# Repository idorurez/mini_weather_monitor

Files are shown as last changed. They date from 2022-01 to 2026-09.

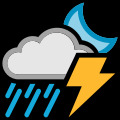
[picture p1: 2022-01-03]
sdcard/47_120x120.jpg

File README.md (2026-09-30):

# Amefuriko — Mini Weather Monitor

After using a really crappy indoor temp and humidity monitor, I wanted to build one for myself to see if I could do better. This is the result. Is it better? I have no idea, but at least it also has a forecast I can trust, built the way I like.

## What it does

* Indoor temperature (°F), humidity, and pressure from a BME280, refreshed every 60 seconds
* Date and time, synced over NTP
* Two-day forecast from Weather Underground: today and tomorrow, with a big icon showing today's weather (sun, clouds, rain, etc.)
* Backlight that follows the room: a BH1750 ambient light sensor drives PWM with smooth ramping, no stepped jumps

## Hardware

* ESP32 devkit (ESP-WROOM-32)
* 4" 480x320 TFT, ST7796 over SPI, run in portrait (320x480)
* BME280 (temp / humidity / pressure) and BH1750 (ambient light) on I2C
* Micro SD card on its own VSPI bus
* Custom PCB and schematic in `pcb/` (KiCad), 3D-printed stand/case models in `model/` (SolidWorks)

Pin map lives in `src/User_Setup.h`. TFT on MOSI 13 / SCLK 14 / CS 15 / DC 26 / RST 32, backlight on GPIO 4 (PWM). SD on VSPI: MOSI 23 / MISO 19 / SCLK 18 / CS 5.

## SD card contents

Everything in `sdcard/` goes on the card root:

* `kozgoprobold*.vlw` — Kozuka Gothic Bold smooth fonts, the UI typeface
* `*_120x120.jpg` — weather icons, named by Weather Underground icon code
* `weather.cfg` — your secrets and location (below). Not in the repo on purpose.

## Configuration

`/weather.cfg` on the SD card, JSON:

```json
{
  "wu_api_key": "your weather underground key",
  "zip": "94070",
  "station_id": "",
  "WIFI": { "hostname": "yokai", "ssid": "your-ssid", "pass": "your-password" },
  "LOCATION": { "latitude": "37.50", "longitude": "-122.34" }
}
```

## Build and flash

PlatformIO project (`platformio.ini` targets `esp32dev`, Arduino framework). Build and upload from VS Code with PlatformIO, or:

```
pio run -t upload
```

Serial monitor at 115200 baud.

## Layout

* `src/` — firmware
* `pcb/` — KiCad schematic and PCB
* `model/` — SolidWorks case/stand models plus a gcode
* `sdcard/` — fonts, weather icons, and config that live on the SD card

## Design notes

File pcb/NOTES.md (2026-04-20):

# PCB Design Notes

Captures intentional design choices and debugging history that aren't
obvious from the schematic alone, plus a TODO list for the next revision.

## Intentional design choices (not bugs)

### J1 wired to UART0 (GPIO1 / GPIO3)
J1 routes the dev kit's `RX0` and `TX0` pins to a 2-pin external header.
This is the **same** UART that the dev kit's onboard CP2102 is permanently
soldered to. Two USB-UARTs on those lines fight each other.

This is **intentional**, not a bug — the convention is: only one of
{onboard CP2102 USB, J1 external UART} should be plugged into a host
at a time. Use one or the other for serial / flashing.

If that convention ever needs to be relaxed (e.g. flash via J1 while
also keeping the onboard USB attached for power), move J1 to
`GPIO16/GPIO17` (RX2/TX2 — currently unconnected per the netlist) and
switch firmware to `Serial2.begin(...)`.

### Two USB-C breakouts (horizontal + vertical)
Both `adafruit_type_c_breakout_rev_b1` (horizontal) and
`adafruit_type_c_vertical_breakout1` (vertical) footprints are placed
intentionally as **mounting alternates**:

- **Horizontal**: desk use; the unit leans on the USB plug.
- **Vertical**: hanging the unit on a wall.

Pick one at assembly time and only solder that one. Both have D+/D-
deliberately unconnected — the breakouts are power-only, since serial /
programming goes through the dev kit's own micro-USB (or J1).

## Power architecture history

The redundant-looking power components (U1 = Pololu S13V30F5,
U3 = Pololu U3V70F5, plus Q1 IRLML6402 P-MOSFET, D1 1N5819 Schottky,
`sj_mini_3v3` jumper) are the result of several revs of brownout / reset
debugging:

- **Brownouts traced partly to mechanical interference**: the TFT's
  on-display SD-card shield was physically touching one of the
  decoupling capacitors on the carrier PCB, causing intermittent
  shorts / brownouts. **Mechanical fix on next rev**: shim or relocate
  the offending cap so it sits well clear of the SD shield's metal
  frame.
- **Multiple regulator footprints** were placed because the Pololu
  modules are expensive and sometimes go out of stock. Having an
  alternate populatable regulator means the board can be assembled
  with whichever is available without a spin.
- **Open solder jumpers** (`sj_Open_onboard_sdcard_*`,
  `sj_onboard_sdcard_clk`) were attempts to wire up the TFT module's
  *own* on-display SD card slot. **Never got it working.** Leave them
  open or remove from next rev to reduce confusion — the project uses
  a separate SD card on VSPI (GPIO5/18/19/23) instead. Forensic
  analysis of why it never mounted is in the section below.

## Why the TFT's onboard SD never mounted

How it was wired (closing the four solder jumpers JP6-JP9 routes the
TFT module's onboard SD card pins to the same ESP32 GPIOs as the
standalone SD on VSPI):

| TFT pad | Jumper | ESP32 GPIO |
|---|---|---|
| `SD_CS` 15 | JP8 | GPIO5 |
| `SD_MOSI` 16 | JP6 | GPIO19 |
| `SD_MISO` 17 | JP7 | GPIO23 |
| `SD_SCK`  18 | JP9 | GPIO18 |

That maps to `User_Setup.h` (`SD_PIN=5, SD_MOSI=23, SD_MISO=19,
SD_SCLK=18`). Firmware-side it should "just work" — TFT itself is on
HSPI (`USE_HSPI_PORT`), SD on VSPI, no bus conflict. So the failure
is hardware-side. Most likely culprits, ranked:

1. **No pull-ups on the SD lines.** SD-mode requires 10-50 kΩ pull-ups
   to 3.3V on `CS`, `MOSI`, `MISO`, `SCK`. None present on the JP6-JP9
   nets in this design, and cheap MSP4021 modules typically don't add
   them on the SD socket either. Without pulls, the card may never
   respond to init — exact symptom: `SD.begin()` returns false.
2. **MISO not tri-stated by the TFT module's onboard SD socket.**
   Notorious gotcha on this class of TFT — the SD's `DO` (MISO) line
   is wired straight to the connector with no tri-state buffer, so the
   card holds the line even when CS is high. Standard fix is a 74HC125
   buffer on MISO.
3. **Brownouts during SD inrush** (~100-300 mA). Same family of issue
   as the documented brownout history. Lacks bulk decoupling near the
   TFT VCC pin.
4. **Solder-jumper reliability** — four hand-bridged SJ pads in series
   on the SD signals; one cold joint kills the whole path. Hard to
   diagnose without per-jumper LEDs/test points.
5. **VSPI default-instance edge cases** — usually fine but worth
   passing an explicit `SPIClass` to `SD.begin()` if revisiting.

### If the TFT-SD path is ever revisited (next rev)
- Add **10 kΩ pull-ups to 3.3V on CS, MOSI, MISO, SCK** between the
  jumpers and the ESP. Single biggest payoff.
- Add a **74HC125 tri-state buffer on MISO** between the TFT module and
  the ESP. Decouples the SD's bad MISO behavior from the bus.
- **Generous decoupling on TFT VCC**: 10 µF tantalum + 100 nF ceramic
  right at TFT pin 1, plus 22 µF on the 3.3V rail near the SD jumpers.
- **Replace solder jumpers with 0Ω resistors or a DIP switch** so
  contact is reliable.

(Practical note: the standalone SD module already works fine for this
project; the TFT-SD path is forensic curiosity, not a real blocker.)

## TODO for next PCB rev

### Strapping-pin pull resistors
- [ ] **10kΩ pull-up on GPIO15 (TFT_CS) to 3.3V.** Without it, GPIO15
      can be low at power-on, which suppresses the ROM bootloader's
      diagnostic log on UART0.
- [ ] **10kΩ pull-down on GPIO12 (TFT_MISO) to GND.** Belt-and-suspenders
      for the flash-voltage strapping. Fine on WROOM-32 modules thanks
      to eFuses, but cheap insurance against bare-chip variants.
- [ ] **10kΩ pull-up on GPIO5 (SD_CS) to 3.3V.** Strapping pin must be
      HIGH at power-on. SD card modules usually pull it up but don't
      rely on it.

### Mechanical / cleanup
- [ ] **TFT SD shield clearance**: ensure no decoupling cap sits under
      the metal frame of the TFT's SD slot — historical brownout source.
- [ ] **External reset button**: wire ESP32 `EN` (Pad 16) to a tactile
      button on the carrier. The dev kit's on-board EN is hard to reach
      once the unit is in an enclosure.
- [ ] **Drop unused TFT on-display SD jumpers** (`sj_Open_onboard_sdcard_*`,
      `sj_onboard_sdcard_clk`) — that path was abandoned.

### Optional improvements
- [ ] **Reduce strapping-pin usage**: TFT and SD currently use three
      strapping pins (GPIO5, GPIO12, GPIO15). Consider re-routing TFT
      pins to GPIO25/26/27/32/33 etc. so boot is less sensitive to what
      external peripherals are doing.
- [ ] **Verify I2C pull-ups** on GPIO21 (SDA) / GPIO22 (SCL): typically
      provided by BME280 / BH1750 breakouts, but worth confirming if
      any breakout is swapped for a bare-chip footprint.
- [ ] **Consider collapsing power architecture** if regulator
      availability has stabilized — fewer parts, fewer failure modes.

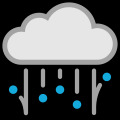
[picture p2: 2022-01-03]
sdcard/17_120x120.jpg

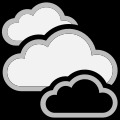
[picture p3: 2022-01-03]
sdcard/20_120x120.jpg

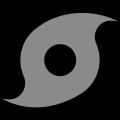
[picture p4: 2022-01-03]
sdcard/01_120x120.jpg

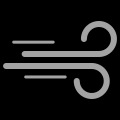
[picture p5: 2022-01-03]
sdcard/23_120x120.jpg

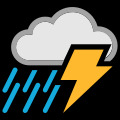
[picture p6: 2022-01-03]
sdcard/38_120x120.jpg

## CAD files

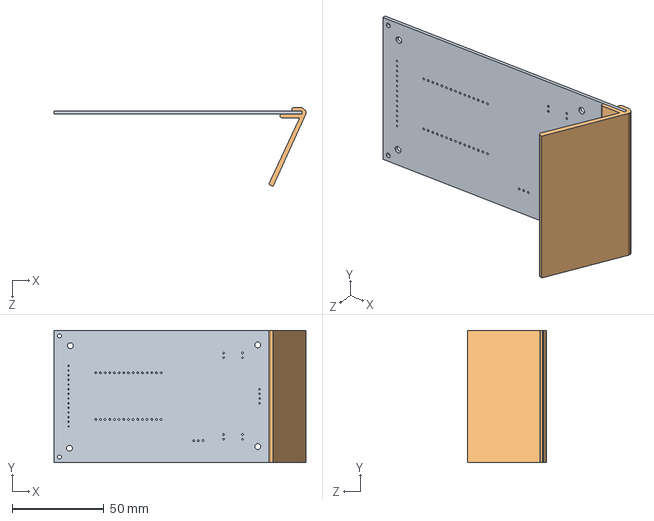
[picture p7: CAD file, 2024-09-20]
model/stand.SLDASM
137.2 x 72.0 x 43.0 mm
mini_weather_monitor PCB
Part1^stand

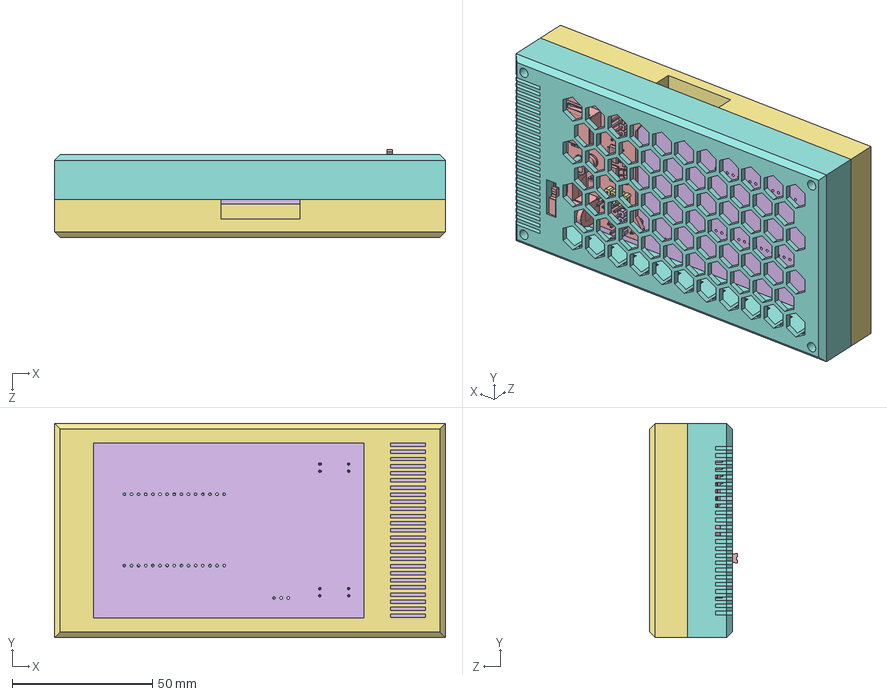
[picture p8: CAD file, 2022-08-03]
model/mini_weather_monitor.SLDASM
139.2 x 76.2 x 31.3 mm
mini_weather_monitor PCB
front_cover^mini_weather_monitor
back_cover^mini_weather_monitor

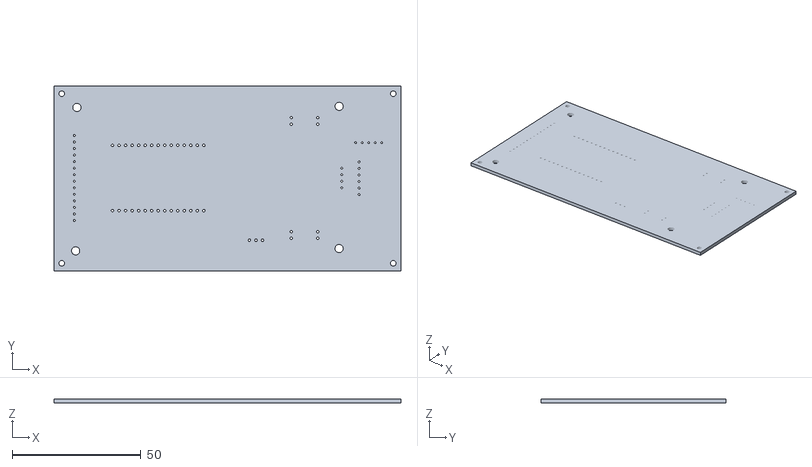
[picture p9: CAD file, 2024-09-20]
model/stl/stand - mini_weather_monitor PCB-1.STL
135.0 x 72.0 x 1.60

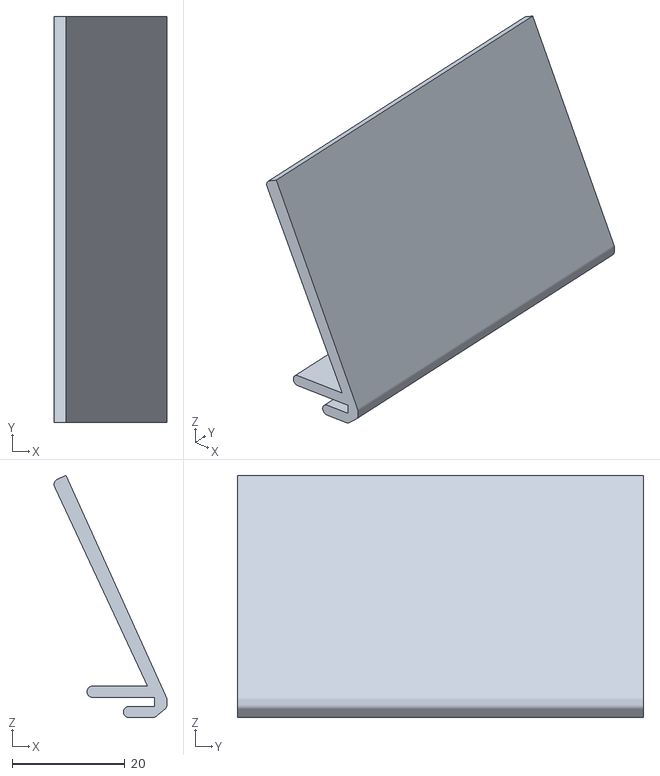
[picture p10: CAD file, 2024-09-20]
model/stl/stand - Part1^stand-1.STL
20.0 x 72.0 x 43.0

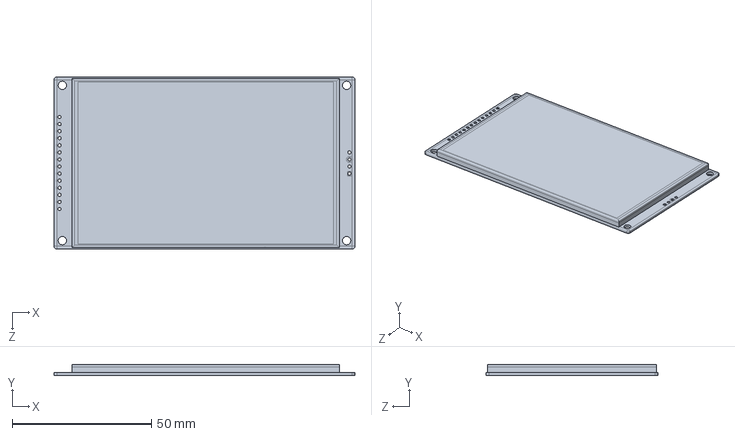
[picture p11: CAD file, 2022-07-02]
model/4.0 inch TFT.SLDPRT
108.0 x 4.10 x 61.7 mm

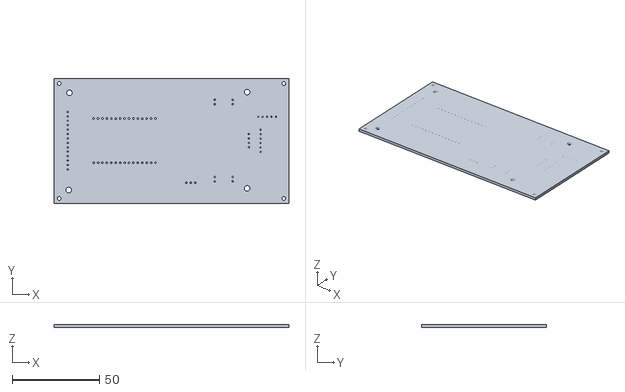
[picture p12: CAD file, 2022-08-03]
model/stl/mini_weather_monitor - mini_weather_monitor PCB-1.STL
135.0 x 72.0 x 1.60

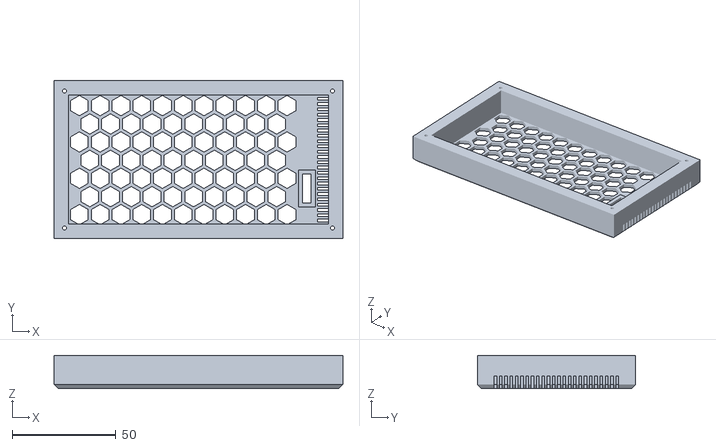
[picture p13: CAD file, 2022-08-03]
model/stl/mini_weather_monitor - back_cover^mini_weather_monitor-1.STL
139.2 x 76.2 x 16.0

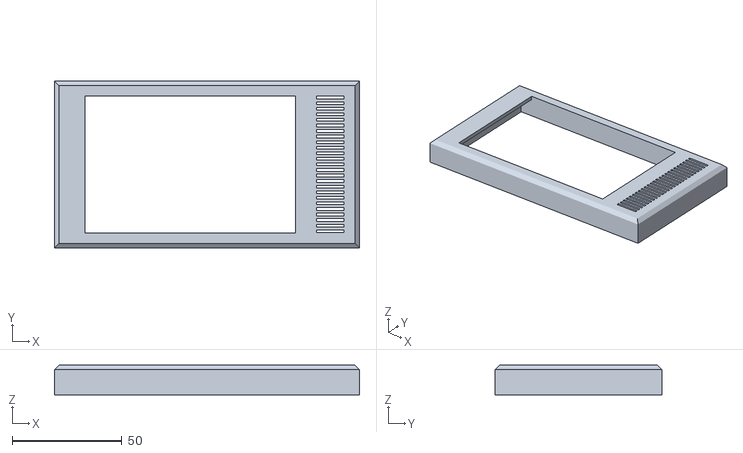
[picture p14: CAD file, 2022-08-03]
model/stl/mini_weather_monitor - front_cover^mini_weather_monitor-1.STL
139.2 x 76.2 x 13.5

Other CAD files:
model/Modelo3D_AR0484.SLDASM
model/case.SLDASM
model/COMPOUND_9.SLDPRT
model/COMPOUND.SLDPRT
model/COMPOUND_3.SLDPRT
model/COMPOUND_6.SLDPRT
model/mini_weather_monitor PCB.SLDPRT
model/COMPOUND_8.SLDPRT
model/COMPOUND_4.SLDPRT
model/COMPOUND_13.SLDPRT
model/COMPOUND_10.SLDPRT
model/COMPOUND_11.SLDPRT
model/COMPOUND_12.SLDPRT
model/COMPOUND_2.SLDPRT
model/COMPOUND_5.SLDPRT
model/COMPOUND_7.SLDPRT
model/stand.SLDPRT
model/stl/stand.STL

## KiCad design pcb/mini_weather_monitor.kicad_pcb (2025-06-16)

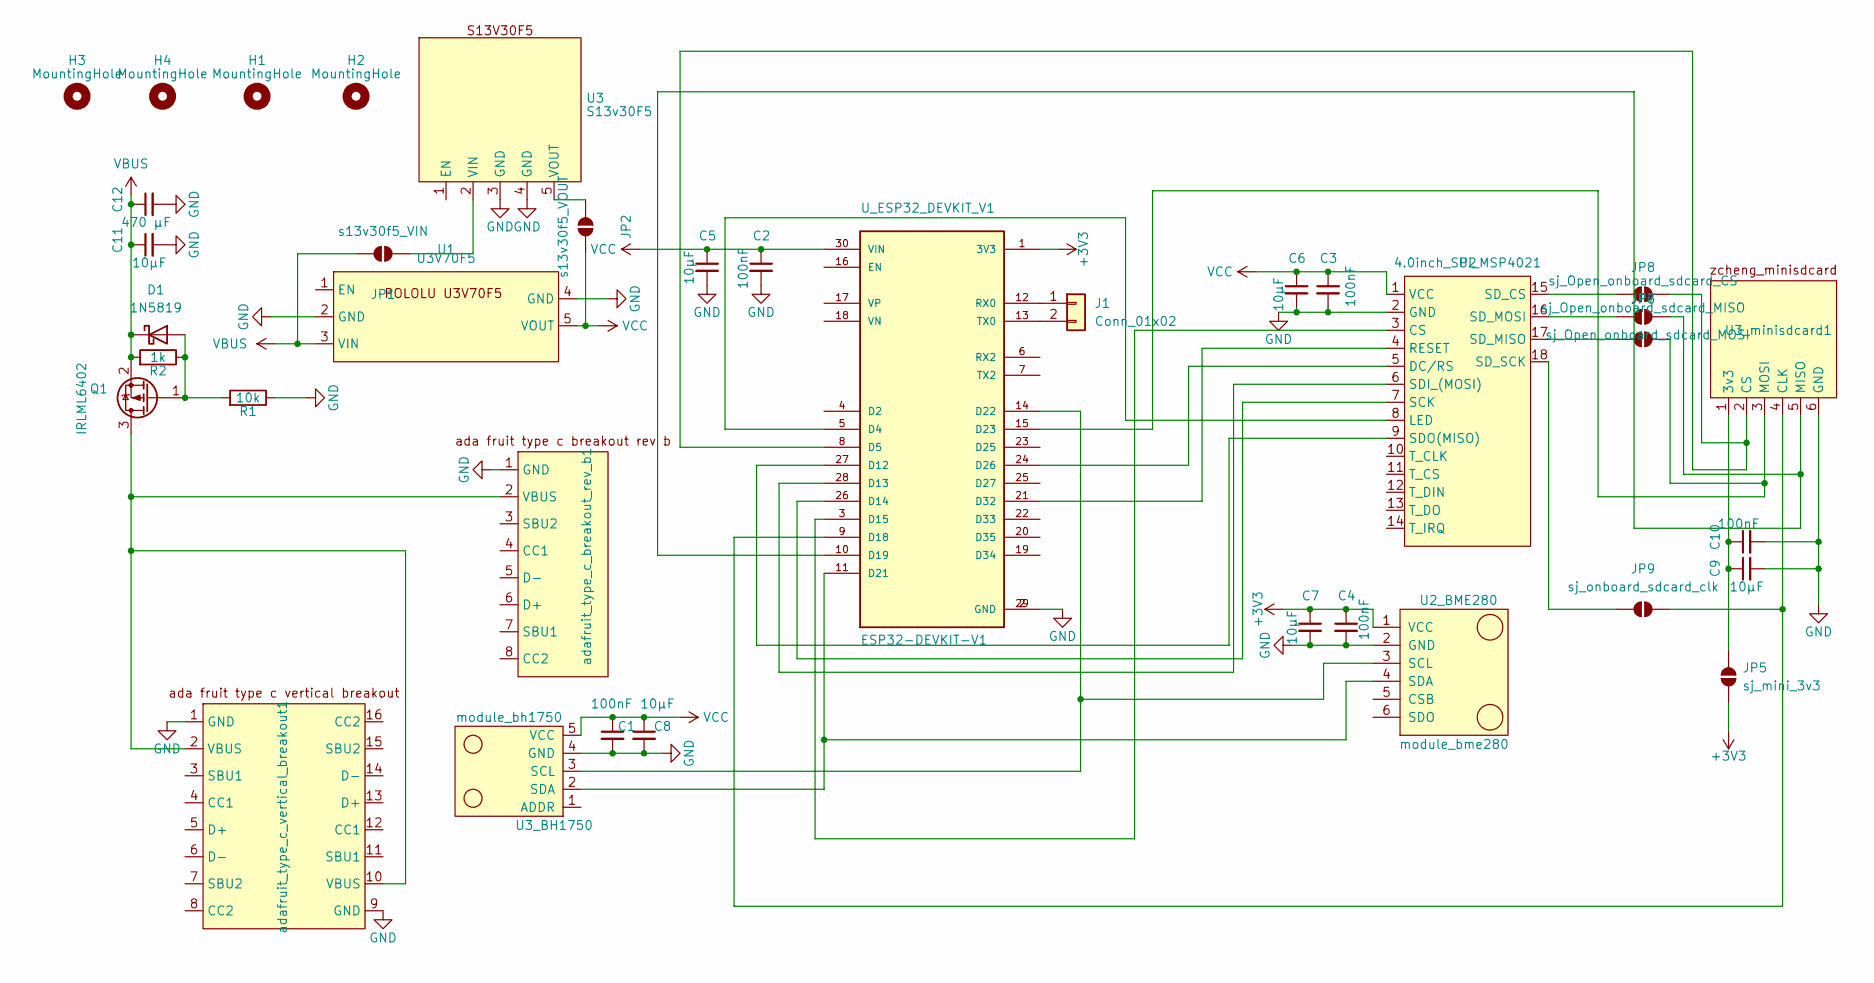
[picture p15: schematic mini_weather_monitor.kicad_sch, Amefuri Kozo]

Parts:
C1, C2, C3, C4, C10: 100nF; C_1206_3216Metric_Pad1.33x1.80mm_HandSolder
C5, C6, C7, C8, C9, C11: 10µF; C_1206_3216Metric_Pad1.33x1.80mm_HandSolder
C12: 470 µF; C_1206_3216Metric_Pad1.33x1.80mm_HandSolder
D1: 1N5819; D_SOD-123
H1, H2, H3, H4: MountingHole; MountingHole_2.2mm_M2
J1: Conn_01x02; PinHeader_1x02_P2.54mm_Vertical
JP1: s13v30f5_VIN; SolderJumper-2_P1.3mm_Open_RoundedPad1.0x1.5mm
JP2: s13v30f5_VOUT; SolderJumper-2_P1.3mm_Open_RoundedPad1.0x1.5mm
JP5: sj_mini_3v3; SolderJumper-2_P1.3mm_Open_RoundedPad1.0x1.5mm
JP6: sj_Open_onboard_sdcard_MOSI; SolderJumper-2_P1.3mm_Open_RoundedPad1.0x1.5mm
JP7: sj_Open_onboard_sdcard_MISO; SolderJumper-2_P1.3mm_Open_RoundedPad1.0x1.5mm
JP8: sj_Open_onboard_sdcard_CS; SolderJumper-2_P1.3mm_Open_RoundedPad1.0x1.5mm
JP9: sj_onboard_sdcard_clk; SolderJumper-2_P1.3mm_Open_RoundedPad1.0x1.5mm
Q1: IRLML6402; SOT-23
R1: 10k; R_1206_3216Metric
R2: 1k; R_1206_3216Metric
U1: U3V70F5; Pololu U3V70F5
U2: 4.0inch_SPI_MSP4021; 4.0inch_SPI
U2_BME280: module_bme280
U3: S13v30F5; pololu S13V30F5 step up step down
U3_BH1750: module_bh1750
U3_minisdcard1: zicheng_mini_sd_card_reader
U_ESP32_DEVKIT_V1: ESP32-DEVKIT-V1; MODULE_ESP32_DEVKIT_V1; PARTREV N/A
adafruit_type_c_breakout_rev_b1: Adafruit_USB_Type_C_Breakout_rev_B
adafruit_type_c_vertical_breakout1: Adafruit_USB_Type_C_Vertical_Breakout

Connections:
+3V3: C4.1, C7.1, JP5.1 (A), U2_BME280.1 (VCC), U_ESP32_DEVKIT_V1.1 (3V3)
GND: C1.2, C2.2, C3.2, C4.2, C5.2, C6.2, C7.2, C8.2, C9.2, C10.2, C11.2, C12.2, R1.1, U1.2 (GND), U1.4 (GND), U2.2 (GND), U2_BME280.2 (GND), U3.3 (GND), U3.4 (GND), U3_BH1750.4 (GND), U3_minisdcard1.6 (GND), U_ESP32_DEVKIT_V1.2 (GND), U_ESP32_DEVKIT_V1.29 (GND), adafruit_type_c_breakout_rev_b1.1 (GND), adafruit_type_c_vertical_breakout1.1 (GND), adafruit_type_c_vertical_breakout1.9 (GND)
unnamed: D1.2 (A), Q1.1 (G), R1.2, R2.1
unnamed: J1.1, U_ESP32_DEVKIT_V1.12 (RX0)
unnamed: J1.2, U_ESP32_DEVKIT_V1.13 (TX0)
unnamed: JP1.1 (A), U3.2 (VIN)
unnamed: JP2.1 (A), U3.5 (VOUT)
unnamed: C9.1, C10.1, JP5.2 (B), U3_minisdcard1.1 (3v3)
unnamed: JP6.1 (A), U2.16 (SD_MOSI)
unnamed: JP6.2 (B), U3_minisdcard1.5 (MISO), U_ESP32_DEVKIT_V1.10 (D19)
unnamed: JP7.1 (A), U2.17 (SD_MISO)
unnamed: JP7.2 (B), U3_minisdcard1.3 (MOSI), U_ESP32_DEVKIT_V1.15 (D23)
unnamed: JP8.1 (A), U2.15 (SD_CS)
unnamed: JP8.2 (B), U3_minisdcard1.2 (CS), U_ESP32_DEVKIT_V1.8 (D5)
unnamed: JP9.1 (A), U2.18 (SD_SCK)
unnamed: JP9.2 (B), U3_minisdcard1.4 (CLK), U_ESP32_DEVKIT_V1.9 (D18)
unnamed: Q1.3 (D), adafruit_type_c_breakout_rev_b1.2 (VBUS), adafruit_type_c_vertical_breakout1.2 (VBUS), adafruit_type_c_vertical_breakout1.10 (VBUS)
unnamed: U2.3 (CS), U_ESP32_DEVKIT_V1.3 (D15)
unnamed: U2.5 (DC/RS), U_ESP32_DEVKIT_V1.24 (D26)
unnamed: U2.8 (LED), U_ESP32_DEVKIT_V1.5 (D4)
unnamed: U2.4 (RESET), U_ESP32_DEVKIT_V1.21 (D32)
unnamed: U2.7 (SCK), U_ESP32_DEVKIT_V1.26 (D14)
unnamed: U2.6 (SDI_(MOSI)), U_ESP32_DEVKIT_V1.28 (D13)
unnamed: U2.9 (SDO(MISO)), U_ESP32_DEVKIT_V1.27 (D12)
unnamed: U2_BME280.3 (SCL), U3_BH1750.3 (SCL), U_ESP32_DEVKIT_V1.14 (D22)
unnamed: U2_BME280.4 (SDA), U3_BH1750.2 (SDA), U_ESP32_DEVKIT_V1.11 (D21)
VBUS: C11.1, C12.1, D1.1 (K), JP1.2 (B), Q1.2 (S), R2.2, U1.3 (VIN)
VCC: C1.1, C2.1, C3.1, C5.1, C6.1, C8.1, JP2.2 (B), U1.5 (VOUT), U2.1 (VCC), U3_BH1750.5 (VCC), U_ESP32_DEVKIT_V1.30 (VIN)

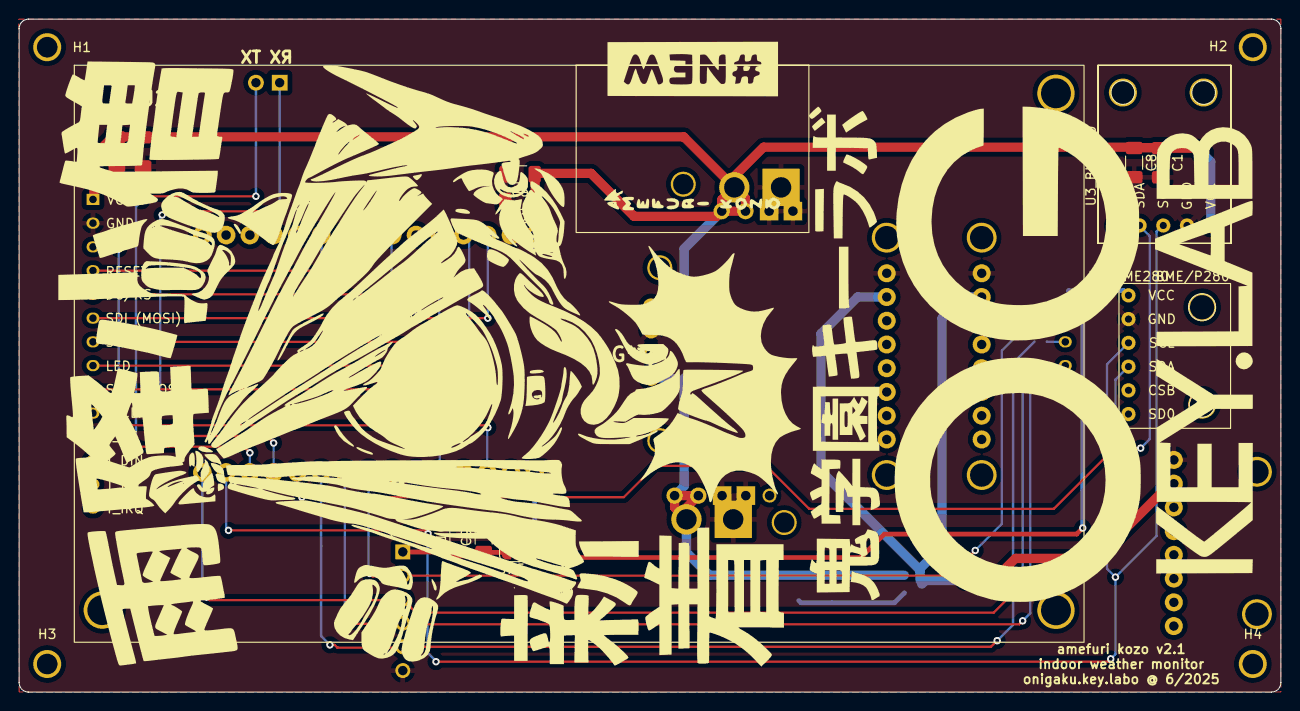
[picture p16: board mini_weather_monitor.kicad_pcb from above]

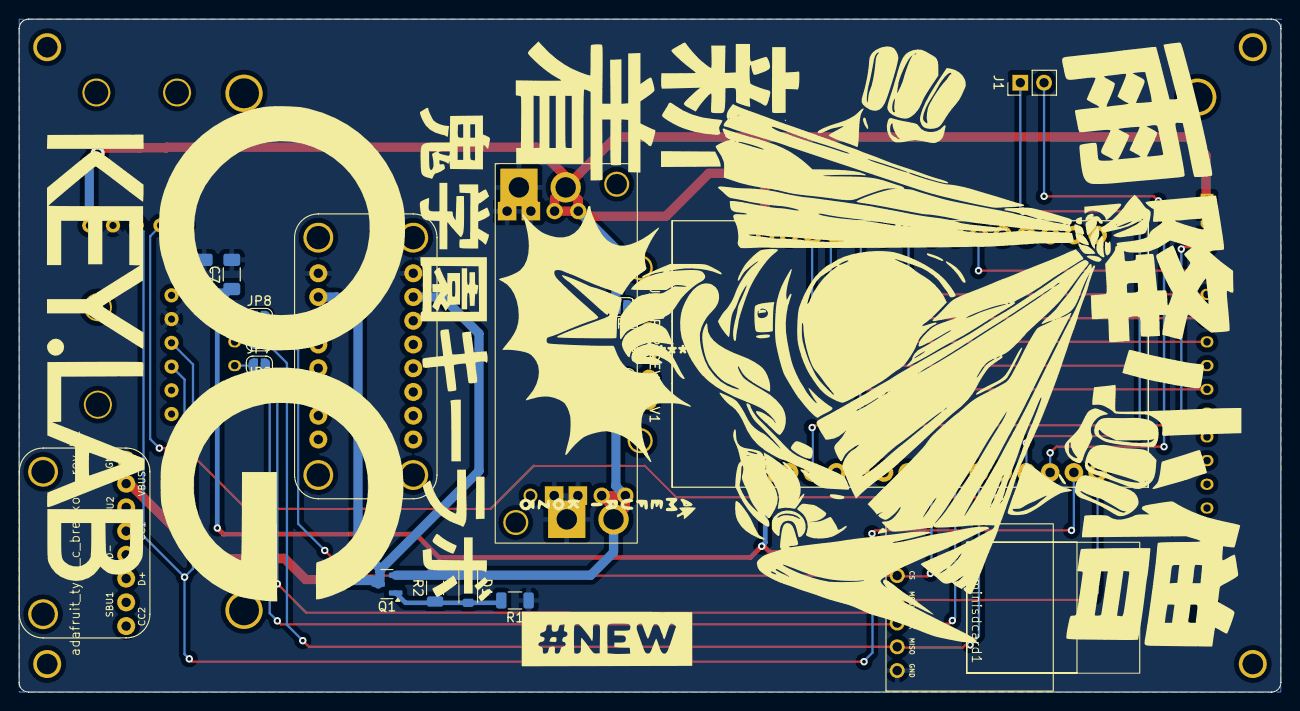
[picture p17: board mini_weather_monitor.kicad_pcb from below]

Board: 2 copper layers, 135.0 x 72.0 mm, 35 parts (19 on the bottom side), 28 nets.

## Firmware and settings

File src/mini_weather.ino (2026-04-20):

/*
 * Hardware:
 * - ESP-WROOM-32 devkit
 * - 4" 480x320 TFT (ST7796) on HSPI; pins in src/User_Setup.h
 * - SD card on VSPI (separate bus from TFT)
 * - BME280 + BH1750 on I2C
 * Pin map in src/User_Setup.h. Runtime config (api keys, ssid, geo) on SD as /weather.cfg.
 */
#include <TFT_eSPI.h>
#include <SPI.h>
#include "SD.h"
#include "time.h"
#include <esp_task_wdt.h>

#include <Wire.h>
#include <ArduinoJson.h>
#include <Adafruit_Sensor.h>
#include <Adafruit_BME280.h>
#include <BH1750.h>
#include <JPEGDecoder.h>
#include <Wifi.h>

#define LED_BUILTIN   2  //Diagnostics using built-in LED

// timeout after 60 seconds
#define WDT_TIMEOUT 60

// === backlight screen pwm
// Target = what the light sensor wants right now.
// Current = where the backlight actually is; glides toward target via pwmStep().
// Both start at a visible default so the boot splash shows up before the
// light sensor's first reading lands; the lux loop will adjust from there.
int   pwmTarget  = 35;
float pwmCurrent = 35;
unsigned long pwmStepTime = 0;
const unsigned long pwmStepDelay = 20;  // ms between ramp steps
const float pwmSmoothing = 0.12;        // 0..1; higher = faster fade

// BME280
#define SEALEVELPRESSURE_HPA (1013.25)
#define BME280_TEMP_ADJUST -2

Adafruit_BME280 bme; // I2C

const unsigned long bmeUpdateDelay     = 60UL * 1000;        // 60s
const unsigned long weatherUpdateDelay = 30UL * 60 * 1000;   // 30min
const unsigned long timeUpdateDelay    = 1000;               // 1s
const unsigned long heapLogDelay       = 60UL * 1000;        // 60s

unsigned long bmeUpdateTime = 0;
unsigned long weatherUpdateTime = 0;
unsigned long timeUpdateTime = 0;
unsigned long heapLogTime = 0;
unsigned long currTime;

// BH1750 I2C
BH1750 lightMeter(0x23);
float lux;
#define DARK 5

TFT_eSPI tft = TFT_eSPI();
TFT_eSprite spr_pressure = TFT_eSprite(&tft);
TFT_eSprite spr_time = TFT_eSprite(&tft);
TFT_eSprite spr_location = TFT_eSprite(&tft);

const char* ntpServer = "pool.ntp.org";
const long  gmtOffset_sec = -28800;
const int   daylightOffset_sec = 3600;

struct WeatherConfig  {
  char wu_api_key[64];
  char zip[10];
  char station_id[32];
  char hostname[64];
  char ssid[64];
  char pass[64];
  char latitude[16];
  char longitude[16];
};

WeatherConfig config; 

// Owned char buffers — values survive the JsonDocument that produced them.
struct ForecastParsed {
  bool  valid;
  char  dayOfWeek[16];
  char  dayPartName[16];
  int   temperature;
  int   temperatureMax;
  int   temperatureMin;
  int   precipChance;
  float qpf;
  float windSpeed;
  char  windDirectionCardinal[8];
  char  wxPhraseShort[40];
  int   iconCode;
  char  uvDescription[16];
  int   uvIndex;
};

ForecastParsed today, tonight, tomorrow;

struct Location {
  bool valid;
  char neighborhood[48];
  char city[48];
  char state[8];
};

Location location;

// Network/screen state surfaced from wifi + fetch layers.
enum NetState {
  NET_OK,
  NET_WIFI_FAILED,
  NET_CAPTIVE_PORTAL,
  NET_FETCH_FAILED
};

NetState netState = NET_OK;

// Outcome of an HTTP fetch. `detail` carries a short human-readable reason
// for the on-screen banner AND the SD log — "HTTP 302", "JSON invalid", etc.
struct FetchResult {
  bool ok;
  int  httpCode;
  char detail[40];
};

enum ForecastReq {
  FIVEDAY,
  CURRENT
};

// Append a timestamped line to /weather.log (and mirror to Serial).
// Used when we can't see serial live — e.g. at work, where the device runs
// headless and we want a postmortem when we get home.
//
// SD.open(FILE_APPEND) doesn't reliably auto-create the file across versions
// of the arduino-esp32 SD library. If append fails we fall back to FILE_WRITE
// (which always creates) so the very first call seeds the file.
void logEvent(const char* fmt, ...) {
  char line[160];
  int n = snprintf(line, sizeof(line), "[%lu] ", millis());
  va_list ap;
  va_start(ap, fmt);
  vsnprintf(line + n, sizeof(line) - n, fmt, ap);
  va_end(ap);

  Serial.println(line);
  bootStatus(line);  // visible on TFT until bootDone() is called

  File f = SD.open("/weather.log", FILE_APPEND);
  if (!f) {
    f = SD.open("/weather.log", FILE_WRITE);
  }
  if (f) {
    f.println(line);
    f.close();
  } else {
    Serial.println("  [logEvent] SD write failed");
  }
}

enum Orientation {
  PORTRAIT = 2,
  LANDSCAPE = 3,
};

const Orientation oriented = PORTRAIT;
const int TFT_W = 320;
const int TFT_H = 480;

// Refresh weather + location, updating netState and screen banners as needed.
static void doWeatherRefresh() {
  bootStatus("Refresh: enter");
  if (!wifiConnect()) {
    netState = NET_WIFI_FAILED;
    logEvent("wifi: failed to connect to %s", config.ssid);
    drawNetBanner(netState, config.ssid);
    return;
  }
  logEvent("wifi: connected %s ip=%s", config.ssid, WiFi.localIP().toString().c_str());

  if (isBehindCaptivePortal()) {
    netState = NET_CAPTIVE_PORTAL;
    drawNetBanner(netState, nullptr);
    return;
  }
  FetchResult fr = refreshForecast();
  FetchResult lr = refreshLocation();
  if (fr.ok && lr.ok) {
    netState = NET_OK;
    bootDone();   // wipe boot log; weather UI takes over from here
    clearNetBanner();
    drawForecast();
    drawLocation();
  } else {
    netState = NET_FETCH_FAILED;
    // Prefer the forecast detail; fall back to location's if forecast was ok.
    drawNetBanner(netState, fr.ok ? lr.detail : fr.detail);
  }
}

void setup(void) {
  Serial.begin(115200);
  BlinkLED(1);

  pinMode(LED_BUILTIN, OUTPUT);
  digitalWrite(LED_BUILTIN, LOW);
  digitalWrite(TFT_CS, HIGH);
  digitalWrite(TFT_BL, HIGH);
  digitalWrite(SD_PIN, HIGH);

  tft.init();
  tft.setRotation(oriented);
  tft.invertDisplay(0);
  tft.fillScreen(TFT_BLACK);
  bootStatus("Boot...");

  if (!SD.begin(SD_PIN)) {
    Serial.println("Card Mount Failed");
    bootStatus("SD: mount FAILED");
    BlinkLED(2);
  } else {
    bootStatus("SD: mounted");
  }

  Wire.end();
  Wire.begin();
  Wire.setClock(100000);

  ledcAttachPin(TFT_BL, PWM1_CH);
  ledcSetup(PWM1_CH, PWM1_FREQ, PWM1_RES);
  ledcWrite(PWM1_CH, (int)pwmCurrent);

  uint8_t cardType = SD.cardType();
  if (cardType == CARD_NONE) {
    Serial.println("No SD card attached");
  }
  uint64_t cardSize = SD.cardSize() / (1024 * 1024);
  Serial.printf("SD Card Size: %lluMB\n", cardSize);

  GetSetConfig();
  bootStatus(config.ssid[0] ? "Config: loaded" : "Config: missing!");

  if (!lightMeter.begin(BH1750::CONTINUOUS_HIGH_RES_MODE)) {
    Serial.println(F("BH1750 init failed"));
    bootStatus("BH1750: FAILED");
  } else {
    bootStatus("BH1750: ok");
  }

  if (!bme.begin(0x76)) {
    Serial.printf("BME280 init failed (sensorID=0x%x)\n", bme.sensorID());
    bootStatus("BME280: FAILED");
  } else {
    bootStatus("BME280: ok");
  }
  bme.setSampling(Adafruit_BME280::MODE_FORCED,
                  Adafruit_BME280::SAMPLING_X1,
                  Adafruit_BME280::SAMPLING_X1,
                  Adafruit_BME280::SAMPLING_X1,
                  Adafruit_BME280::FILTER_OFF);
  bootStatus("BME: sampling set");
  bme.takeForcedMeasurement();
  bootStatus("BME: first read ok");

  tft.invertDisplay(0);
  tft.setTextDatum(MC_DATUM);
  tft.setTextColor(TFT_WHITE);
  bootStatus("Pre-blink");
  BlinkLED(3);
  bootStatus("Post-blink");

  // Watchdog covers the long blocking sections (wifi associate, http fetch).
  esp_task_wdt_init(WDT_TIMEOUT, true);
  esp_task_wdt_add(NULL);
  bootStatus("WDT armed, refreshing...");

  doWeatherRefresh();
  weatherUpdateTime = millis();

  displayIndoorConditions(bme.readTemperature(), bme.readPressure(), bme.readHumidity());
  configTime(gmtOffset_sec, daylightOffset_sec, ntpServer);

  currTime = millis();
  bmeUpdateTime = currTime;
  timeUpdateTime = currTime;
  heapLogTime = currTime;

  BlinkLED(4);
}

void loop() {
  esp_task_wdt_reset();
  bme.takeForcedMeasurement();

  if (lightMeter.measurementReady()) {
    lux = lightMeter.readLightLevel();
    int target = (int)(0.85 * lux) + 1;
    pwmTarget = constrain(target, 1, 90);
  }

  currTime = millis();

  // Glide pwmCurrent toward pwmTarget so brightness changes are smooth, not stepped.
  if ((currTime - pwmStepTime) > pwmStepDelay) {
    pwmStepTime = currTime;
    float delta = (float)pwmTarget - pwmCurrent;
    if (fabsf(delta) < 0.5f) {
      pwmCurrent = pwmTarget;
    } else {
      pwmCurrent += delta * pwmSmoothing;
    }
    ledcWrite(PWM1_CH, (int)(pwmCurrent + 0.5f));
  }

  if ((currTime - bmeUpdateTime) > bmeUpdateDelay) {
    displayIndoorConditions(bme.readTemperature(), bme.readPressure(), bme.readHumidity());
    bmeUpdateTime = currTime;
  }

  if ((currTime - weatherUpdateTime) > weatherUpdateDelay) {
    doWeatherRefresh();
    weatherUpdateTime = currTime;
  }

  if ((currTime - timeUpdateTime) > timeUpdateDelay) {
    printLocalTime(0, 175);
    timeUpdateTime = currTime;
  }

  if ((currTime - heapLogTime) > heapLogDelay) {
    Serial.printf("[heap] free=%u min=%u\n", ESP.getFreeHeap(), ESP.getMinFreeHeap());
    heapLogTime = currTime;
  }
}

void GetSetConfig() {
  File configFile = SD.open("/weather.cfg", FILE_READ);
  if (configFile) {
    const size_t capacity = 4096;
    DynamicJsonDocument doc(capacity);
    DeserializationError error = deserializeJson(doc, configFile);
    if (error) {
      Serial.print(F("Failed to read file, using default configuration. Error: "));
      Serial.println(error.f_str());
    } else {
      strlcpy(config.wu_api_key, doc["wu_api_key"] | "", sizeof(config.wu_api_key));
      strlcpy(config.zip,        doc["zip"]        | "", sizeof(config.zip));
      strlcpy(config.station_id, doc["station_id"] | "", sizeof(config.station_id));
      strlcpy(config.hostname,   doc["WIFI"]["hostname"] | "", sizeof(config.hostname));
      strlcpy(config.ssid,       doc["WIFI"]["ssid"]     | "", sizeof(config.ssid));
      strlcpy(config.pass,       doc["WIFI"]["pass"]     | "", sizeof(config.pass));
      strlcpy(config.latitude,   doc["LOCATION"]["latitude"] | "", sizeof(config.latitude));
      strlcpy(config.longitude,  doc["LOCATION"]["longitude"] | "", sizeof(config.longitude));
     }
     configFile.close();
  } else {
    Serial.println(F("Failed to open config file"));
  }
}

void BlinkLED(int num)
{
  int x;
  //if reason code =0, then set num =1 (just so I can see something)
  if (!num)
  {
    num = 1;
  }
  for (x = 0; x < num; x++)
  {
    //LED ON
    digitalWrite(LED_BUILTIN, HIGH);
    delay(200);
    //LED OFF
    digitalWrite(LED_BUILTIN, LOW);
    delay(100);
  }
  delay(1000);
}

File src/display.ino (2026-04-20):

#define AA_FONT_14 "kozgoprobold14"
#define AA_FONT_15 "kozgoprobold15"
#define AA_FONT_30 "kozgoprobold30"
#define AA_FONT_35 "kozgoprobold35"
#define AA_FONT_40 "kozgoprobold40"
#define AA_FONT_45 "kozgoprobold45"
#define AA_FONT_48 "kozgoprobold48"
#define AA_FONT_55 "kozgoprobold55"
#define AA_FONT_65 "kozgoprobold65"
#define AA_FONT_90 "kozgoprobold90"
#define AA_FONT_115 "kozgoprobold115"

// Time-area sprite dimensions; the auto-shrink uses width - margin as the budget.
static const int kTimeSpriteW = 270;
static const int kTimeMargin  = 10;  // 5px cursor + 5px right slack

// ---- boot status overlay --------------------------------------------------
// Renders short status lines on the TFT during early boot so we have a
// visible "terminal" without needing serial. bootStatus() is a no-op once
// bootDone() has been called; bootDone() wipes the screen so the steady-state
// weather UI can render onto a clean surface.
static int   bootLineY     = 0;
static const int kBootLineH = 18;        // px between rows when using textSize 2
static bool  bootActive    = true;

void bootStatus(const char* line) {
  if (!bootActive) return;
  if (bootLineY + kBootLineH > TFT_H) {
    tft.fillScreen(TFT_BLACK);
    bootLineY = 0;
  }
  tft.setTextSize(2);                 // built-in 5x8 font * 2 — no SD needed
  tft.setTextColor(TFT_WHITE, TFT_BLACK);
  tft.setTextDatum(TL_DATUM);
  tft.setCursor(5, bootLineY);
  tft.print(line);
  tft.setTextSize(1);                 // restore default
  tft.setTextDatum(MC_DATUM);         // restore the default this project uses
  bootLineY += kBootLineH;
}

void bootDone() {
  if (!bootActive) return;
  bootActive = false;
  tft.fillScreen(TFT_BLACK);
}

// Pick the largest font that fits `text` within `budgetPx`, with per-call caching.
// Callers pass a cacheText buffer + cacheFont pointer so the measurement loop runs
// only when the rendered string changes (once a day for %A and %B %d, not once a second).
// On cache hit we just reload the previously-chosen font for rendering.
static void loadLargestFitting(TFT_eSprite& spr, const char* text, int budgetPx,
                               const char* const* fonts, int n,
                               char* cacheText, size_t cacheSize,
                               const char** cacheFont) {
  if (*cacheFont && strcmp(text, cacheText) == 0) {
    spr.loadFont(*cacheFont);
    return;
  }
  strlcpy(cacheText, text, cacheSize);
  for (int i = 0; i < n; i++) {
    spr.loadFont(fonts[i]);
    int w = spr.textWidth(text);
    if (w <= budgetPx || i == n - 1) {
      if (i > 0 && w <= budgetPx) {
        Serial.printf("  fit '%s' -> %s (%dpx, budget %d)\n", text, fonts[i], w, budgetPx);
      } else if (w > budgetPx) {
        Serial.printf("  overflow '%s' @ %s = %dpx (budget %d)\n", text, fonts[i], w, budgetPx);
      }
      *cacheFont = fonts[i];
      return;
    }
  }
}

// Banner band shown under the time area when weather can't be reached.
static const int kBannerY = 320;
static const int kBannerH = 30;

void clearNetBanner() {
  tft.fillRect(0, kBannerY, TFT_W, kBannerH, TFT_BLACK);
}

// `detail` appends a short reason to the banner when relevant (HTTP code,
// JSON error, SSID, etc). Pass nullptr to omit.
void drawNetBanner(NetState state, const char* detail) {
  char buf[80];
  const char* msg = "";
  uint16_t color = TFT_RED;
  switch (state) {
    case NET_WIFI_FAILED:
      snprintf(buf, sizeof(buf), "WiFi failed: %.40s", detail ? detail : "");
      msg = buf;
      break;
    case NET_CAPTIVE_PORTAL:
      msg = "Captive portal";
      color = TFT_YELLOW;
      break;
    case NET_FETCH_FAILED:
      snprintf(buf, sizeof(buf), "Fetch: %.40s", detail ? detail : "unknown");
      msg = buf;
      color = TFT_ORANGE;
      break;
    default:
      return;
  }
  tft.fillRect(0, kBannerY, TFT_W, kBannerH, TFT_BLACK);
  tft.loadFont(AA_FONT_15, SD);
  tft.setTextDatum(MC_DATUM);
  tft.setTextColor(color, TFT_BLACK);
  tft.drawString(msg, TFT_W / 2, kBannerY + kBannerH / 2);
  tft.unloadFont();
}

void printLocalTime(int x, int y) {
  struct tm timeinfo;
  if (!getLocalTime(&timeinfo)) {
    Serial.println("Failed to obtain time");
    return;
  }

  spr_time.setColorDepth(8);
  spr_time.createSprite(270, 160);
  spr_time.fillSprite(TFT_BLACK);

  spr_time.loadFont(AA_FONT_65);
  spr_time.setTextColor(lux > DARK ? TFT_ORANGE : TFT_WHITE);
  spr_time.setCursor(5, 0);
  spr_time.println(&timeinfo, "%H:%M:%S");

  spr_time.setTextColor(TFT_MAGENTA);
  spr_time.setCursor(5, 58);
  char dayBuf[20];
  strftime(dayBuf, sizeof(dayBuf), "%A", &timeinfo);
  static const char* const dayFonts[] = {AA_FONT_55, AA_FONT_48, AA_FONT_45};
  static char dayCacheText[16] = {0};
  static const char* dayCacheFont = nullptr;
  loadLargestFitting(spr_time, dayBuf, kTimeSpriteW - kTimeMargin,
                     dayFonts, 3, dayCacheText, sizeof(dayCacheText), &dayCacheFont);
  spr_time.println(dayBuf);

  spr_time.setTextColor(TFT_WHITE);
  spr_time.setCursor(5, 115);
  char dateBuf[32];
  strftime(dateBuf, sizeof(dateBuf), "%B %d", &timeinfo);
  static const char* const dateFonts[] = {AA_FONT_45, AA_FONT_40, AA_FONT_35, AA_FONT_30};
  static char dateCacheText[32] = {0};
  static const char* dateCacheFont = nullptr;
  loadLargestFitting(spr_time, dateBuf, kTimeSpriteW - kTimeMargin,
                     dateFonts, 4, dateCacheText, sizeof(dateCacheText), &dateCacheFont);
  spr_time.println(dateBuf);

  spr_time.pushSprite(x, y);
  spr_time.deleteSprite();
}

void displayIndoorConditions(float te, float pe, float he) {
  float tempF = ((te * 9 / 5) + 32) + BME280_TEMP_ADJUST;

  tft.fillRect(0, 0, TFT_W, 175, TFT_BLACK);
  tft.setTextColor(TFT_WHITE);

  tft.setCursor(5, 0);
  tft.loadFont(AA_FONT_115, SD);
  tft.print(tempF, 1);
  tft.println("°");

  tft.loadFont(AA_FONT_90, SD);
  tft.setCursor(5, 95);
  tft.print(he, 1);
  tft.println("%");
  drawPressure(pe);
}

void drawPressure(float pressure) {
  float pe = pressure / 100.0;

  spr_pressure.setColorDepth(16);
  spr_pressure.createSprite(180, 24);
  tft.setPivot(280, 0);
  spr_pressure.setPivot(0, 28);
  spr_pressure.fillSprite(TFT_BLACK);
  spr_pressure.setTextColor(TFT_SKYBLUE, TFT_BLACK);
  spr_pressure.loadFont(AA_FONT_30, SD);
  spr_pressure.drawString(String(pe) + " hPA", 0, 0);
  spr_pressure.pushRotated(90);
  spr_pressure.unloadFont();
  spr_pressure.deleteSprite();
}
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

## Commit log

2022-01-02 added readme and stuff
    [indoor_weather_monitor.kicad_pcb, indoor_weather_monitor.kicad_sch]
2022-01-05 adding bh1750 to sense light to dim lcd. moved a pin or two to accommodate i2c
2022-01-06 working on separate current conditions display
    [indoor_weather_monitor.kicad_sch]
2022-01-13 tooling around with placement
    [indoor_weather_monitor.kicad_pcb, indoor_weather_monitor.kicad_sch]
2022-01-15 repositioning local forecast
    [indoor_weather_monitor.kicad_pcb]
2022-01-24 updated pcb and everything is working so far
    [indoor_weather_monitor.kicad_pcb, indoor_weather_monitor.kicad_sch, mini_weather_monitor.kicad_pcb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]
2022-02-14 wip, with MPU6050, but will switch to SW520D
    [mini_weather_monitor.kicad_pcb, mini_weather_monitor.kicad_sch]
2022-03-11 fixing orientation with new tilt sensor and adding libraries to repo
    [mini_weather_monitor.kicad_pcb, mini_weather_monitor.kicad_sch]
2022-06-02 fixxing footprint and pad
    [mini_weather_monitor.kicad_pcb, mini_weather_monitor.kicad_sch]
2022-06-02 fixxing footprint on power supply
2022-06-02 trace cleanup
    [mini_weather_monitor.kicad_pcb, mini_weather_monitor.kicad_sch]
2022-06-03 updated silkscreen placement and fixes
    [mini_weather_monitor-B_Cu.gbr, mini_weather_monitor-B_Mask.gbr, mini_weather_monitor-B_Paste.gbr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]
2022-06-20 fixing tilt sensor and power connection was not updated from library
    [mini_weather_monitor-B_Cu.gbr, mini_weather_monitor-B_Mask.gbr, mini_weather_monitor-B_Paste.gbr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]
2022-07-02 working after pcb
    [4.0 inch TFT.SLDPRT, COMPOUND.SLDPRT, COMPOUND_10.SLDPRT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]
2022-08-03 latest with 2 degree adjustment
    [mini_weather_monitor - back_cover^mini_weather_monitor-1.STL, mini_weather_monitor - front_cover^mini_weather_monitor-1.STL, mini_weather_monitor - mini_weathe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]
2022-08-18 adding watchdog to reset
    [display.ino, mini_weather.ino]
2024-09-20 working pass, colors, tbd on time bug stop
    [stand - Part1^stand-1.STL, stand - mini_weather_monitor PCB-1.STL, stand.SLDASM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]
2024-10-28 revamping a bit
    [mini_weather_monitor-B_Cu.gbr, mini_weather_monitor-B_Mask.gbr, mini_weather_monitor-B_Paste.gbr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]
2024-10-31 adding extra usb input
    [mini_weather_monitor-B_Cu.gbr, mini_weather_monitor-B_Mask.gbr, mini_weather_monitor-B_Paste.gbr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]
2024-11-06 using adafruit stuff
    [mini_weather_monitor.kicad_pcb, mini_weather_monitor.kicad_sch]
2024-11-07 adding caps and diodes
    [mini_weather_monitor.kicad_pcb, mini_weather_monitor.kicad_sch]
2025-03-01 working code. pcb wip
    [mini_weather_monitor-B_Cu.gbr, mini_weather_monitor-B_Mask.gbr, mini_weather_monitor-B_Paste.gbr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]
2025-03-02 set mosfet, schottkey and resistor
    [mini_weather_monitor.kicad_pcb, mini_weather_monitor.kicad_sch]
2025-03-21 adding mini sdcard to use instead of onboard sdcard
    [mini_weather_monitor-B_Cu.gbr, mini_weather_monitor-B_Mask.gbr, mini_weather_monitor-B_Paste.gbr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]
2025-04-29 moved config info to config on sdcard
    [mini_weather_monitor-B_Cu.gbr, mini_weather_monitor-B_Mask.gbr, mini_weather_monitor-B_Paste.gbr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]
2025-05-03 fixing mosfet setup, also updating for day of the week length
    [mini_weather_monitor.kicad_pcb, mini_weather_monitor.kicad_sch, weather.cfg]
2025-06-05 added fonts
    [mini_weather_monitor-B_Cu.gbr, mini_weather_monitor-B_Mask.gbr, mini_weather_monitor-B_Paste.gbr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]
2025-06-05 adding passthrough
    [mini_weather_monitor.kicad_pcb, mini_weather_monitor.kicad_sch]
2025-06-14 slight retrace
    [mini_weather_monitor.kicad_pcb, mini_weather_monitor.kicad_sch]
2025-06-16 fixing forecast parsing and display
    [mini_weather_monitor-B_Cu.gbr, mini_weather_monitor-B_Mask.gbr, mini_weather_monitor-B_Paste.gbr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]
2025-06-27 changed colors, updated pcb
2026-04-19 pcb: rotate auto-saved backup snapshots
2026-04-19 refactor: own parsed strings, harden HTTP, recover gracefully on bad networks
    The "garbled forecast" and "weird data on the monitor" symptoms had three
    overlapping root causes; this rewrites the affected layers to fix them at
    the source rather than papering over.
    - ForecastParsed/Location now hold owned char buffers populated via strlcpy.
    Previously they held const char* pointers into a DynamicJsonDocument that
    was destroyed on function return, so reads after the parse stage hit
    reused heap and rendered garbage.
    - forecast.ino streams http.getStream() directly into ArduinoJson with a
    Filter, dropping the doc footprint from ~14KB to ~6KB and eliminating the
    intermediate Arduino St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
    [JPEG_functions.ino, display.ino, forecast.ino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]
2026-04-19 display: tomorrow-column alignment, fit-cache, smooth backlight
    - drawForecastTomorrow centered text at x+30 which shifted the column
    30px right of where the original stats-only path had it; revert to
    centering at x so short day names like "Sunday" sit under the column
    header instead of scooting right.
    - loadLargestFitting now caches the last-measured text and its chosen
    font. printLocalTime runs once a second; the full measurement loop
    now runs only when the day-of-week or date string actually changes,
    not on every tick. Serial also quiets down: logs only on fallback
    (new smaller font picked) or overflow (no smaller font available).
    - Backlight glides toward its lux-derived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
    [display.ino, mini_weather.ino]
2026-04-20 diagnostics: on-screen boot terminal, SD log, fetch detail in banner
    The Meta visit needs to be diagnosable without a serial cable, since the
    device runs headless there. This commit makes failures self-explaining
    both at-a-glance (TFT banner with the actual failure detail) and after
    the fact (timestamped log on the SD card).
    - New FetchResult { ok, httpCode, detail } returned from fetchJsonFiltered
    / refreshForecast / refreshLocation. Replaces the bool return so the
    detail string ("HTTP 302", "ct=text/html", "JSON: InvalidInput", etc.)
    can flow up to both the banner and the log.
    - drawNetBanner now takes a detail string and renders it: the banner
    shows "Fetch: HTTP 302" / "WiFi fai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
    [User_Setup.h, display.ino, forecast.ino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]
2026-04-20 pcb: design notes — intent, brownout history, TFT-SD postmortem, next-rev TODOs
    Captures context that isn't in the schematic so future-me doesn't
    re-investigate the same things:
    - Why J1 sits on UART0 (intentional one-or-the-other-not-both
    convention with the dev kit's onboard CP2102) and the path to
    loosen that convention if needed.
    - Why both horizontal and vertical USB-C breakouts are placed
    (mounting alternates: desk vs hanging), and that both are
    power-only by design.
    - The brownout history — including the mechanical finding that the
    TFT's onboard SD-card metal shield was shorting against a
    decoupling cap on the carrier — and why the power architecture
    ended up with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
2026-09-30 Simplify feature list to match the actual device
